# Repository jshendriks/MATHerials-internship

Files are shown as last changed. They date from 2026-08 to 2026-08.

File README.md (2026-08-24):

# MATHerials internship
As part of the masters Science Education and Communication at Utrecht University I was an intern at Hogeschool Utrecht at the lectorate of mathematical and analytical faculties for professionals. During the internship I developed a prototype for MATHerials based on a digital action-based embodied design developed and researched by the Freudenthal Institute at Utrecht University (https://embodieddesign.sites.uu.nl/). 

## Main features
The prototype can be used to explore the connection between the x-coordinate of the sine graph and the unit circle. The idea is that a user manipulates two grips, one along a line and the other on a circle. Feedback on the movement of the user is provided by a light (or something else depending on your needs). The feedback mechanism is hidden inside a box. This mechanism uses a pulley system to translate circular movement into linear movement and an electrical circuit. The electrical circuit contains a hall effect which closes the circuit if it is near a magnet. The pulley system indicates the length which needs to be travelled by the grip in the line using a magnet. The magnet on the pulley system closes the electrical circuit. The closed electrical circuit turns on the LED and indicates that the user has correctly moved the grips on the lid of the prototype.

## Build instructions
This repository has three folders, namely:
- Documents
- Hardware
- Results
### Documents
The folder Documents contains documentation on the prototype such as the literature on embodied cognition, mathematics anxiety and the digital action-based embodied design on which the prototype is based. Moreover, this directory also contains the internship report concerning this prototype.
### Hardware
The folder Hardware contains files which can be used to reconstruct the prototype yourself such as the step files for the 3D printed parts and ai files for laser cutting the box and the lid of the box.
### Results
The folder Results contains pictures of the prototype made during the internship.

## Outcomes
The main outcome of the internship is a prototype for a physical action-based embodied design. 

## Funding and guidance
The prototype was funded by @LilisProtoLab (https://github.com/LilisProtoLab) and the Freudenthal Institute. Moreover, while building the prototype I have received guidance and advice on how to build the prototype from the team at @LilisProtoLab. Thank you all so much!

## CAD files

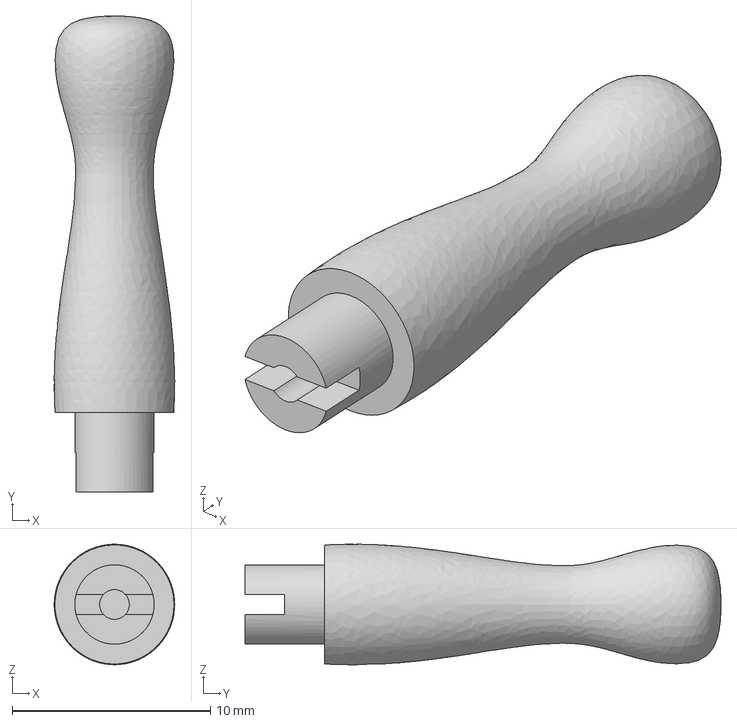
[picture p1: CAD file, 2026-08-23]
Hardware/3D printing/Handle.step
6.08 x 24.0 x 6.08 mm

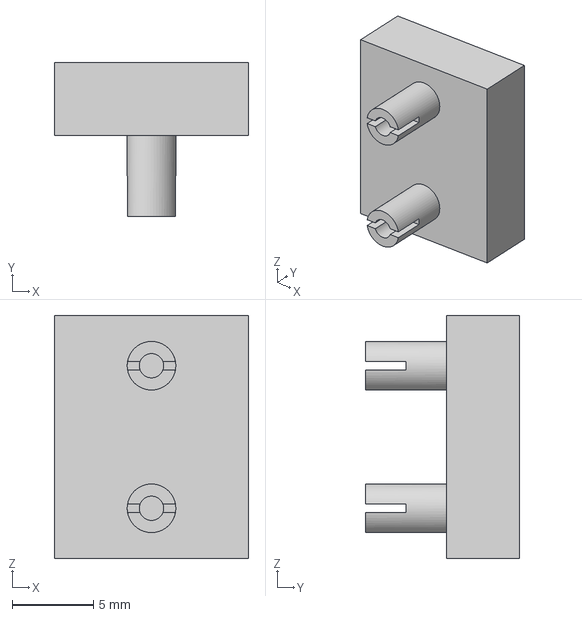
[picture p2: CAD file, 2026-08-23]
Hardware/3D printing/MagnetHolderUpper.step
12.0 x 9.50 x 15.0 mm

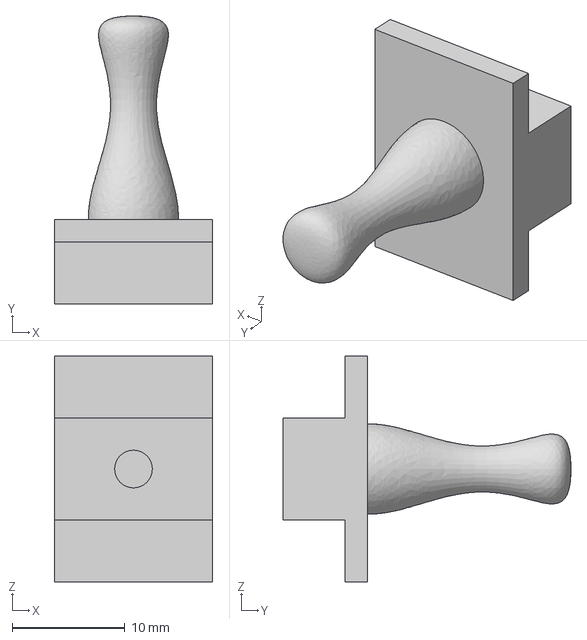
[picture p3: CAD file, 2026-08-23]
Hardware/3D printing/LinearHandleUpper.step
14.0 x 25.5 x 20.0 mm

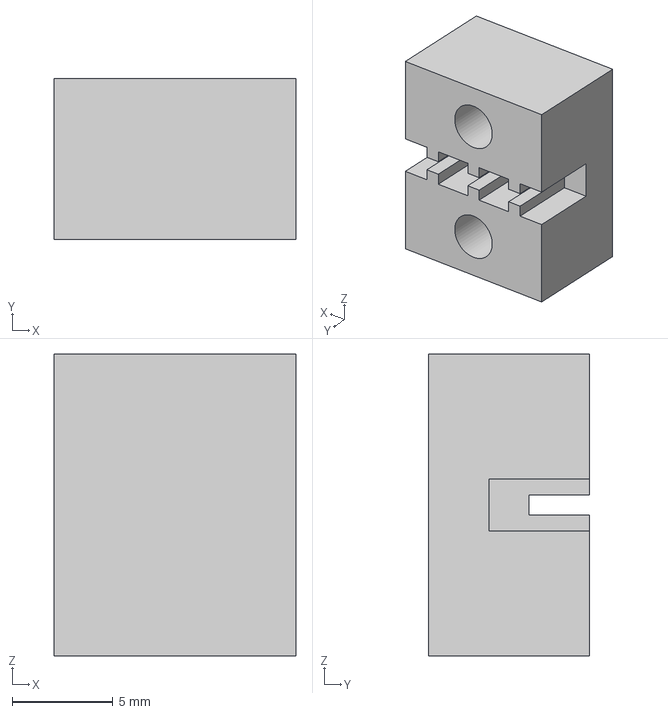
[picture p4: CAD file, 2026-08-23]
Hardware/3D printing/MagnetHolderLower.step
12.0 x 8.00 x 15.0 mm

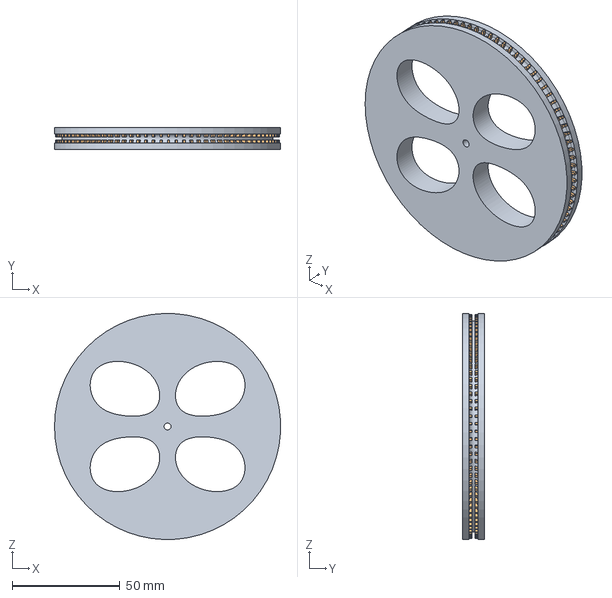
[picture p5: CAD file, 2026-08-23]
Hardware/3D printing/BallPulleyRight.step
104.9 x 10.0 x 105.0 mm

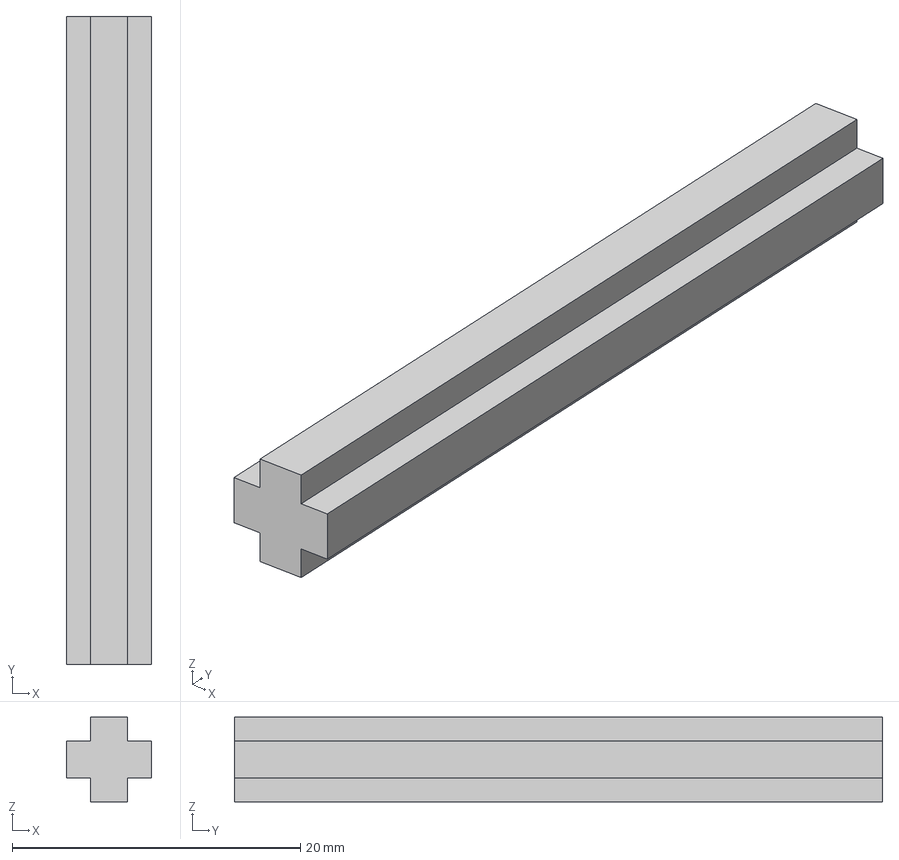
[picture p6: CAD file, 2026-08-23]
Hardware/3D printing/Axle.step
5.90 x 45.0 x 5.90 mm

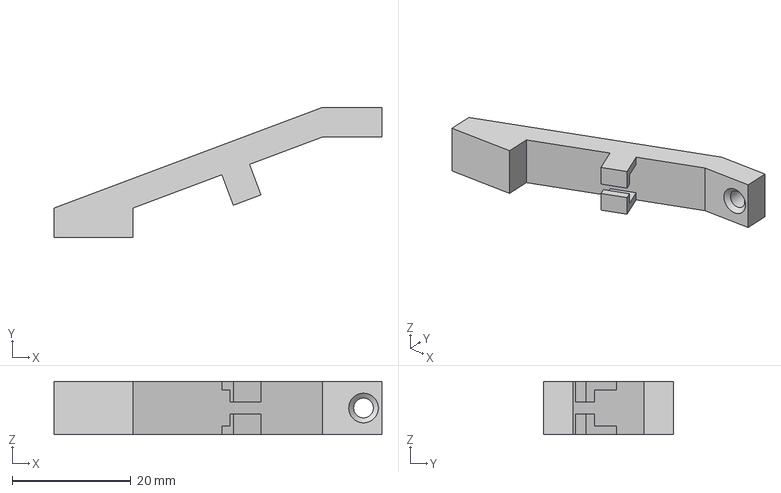
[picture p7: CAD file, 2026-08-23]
Hardware/3D printing/HallEffect.step
55.3 x 22.0 x 9.00 mm

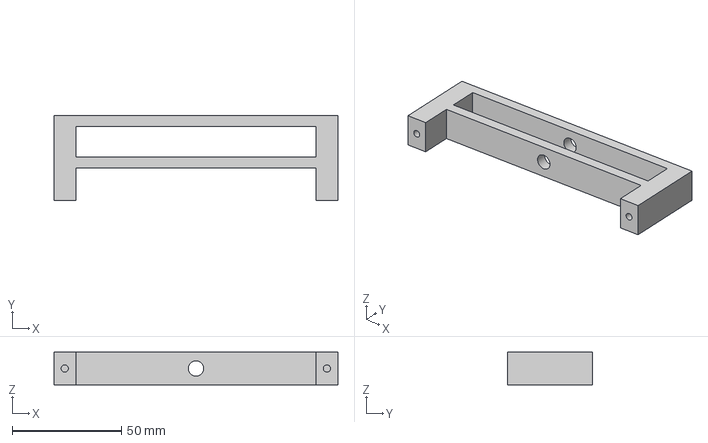
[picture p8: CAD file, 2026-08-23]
Hardware/3D printing/Gearbox.step
130.0 x 39.0 x 15.0 mm

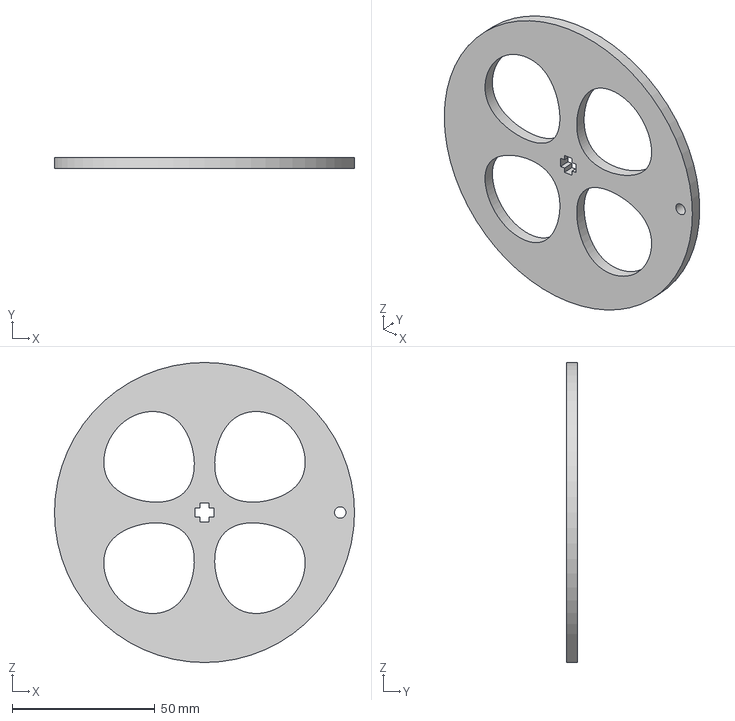
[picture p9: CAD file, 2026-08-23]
Hardware/3D printing/Wheel.step
105.0 x 4.00 x 105.0 mm

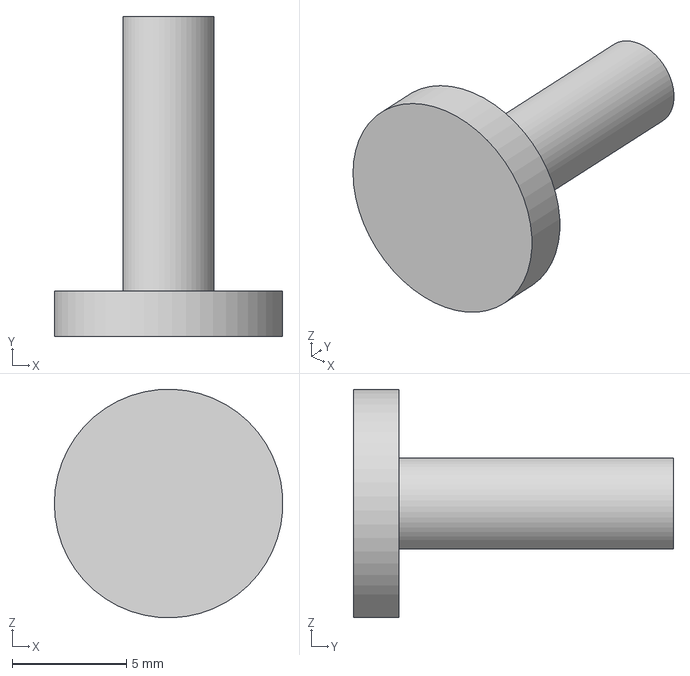
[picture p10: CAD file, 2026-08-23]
Hardware/3D printing/PlaceHolder.step
9.99 x 14.0 x 10.00 mm

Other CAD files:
Hardware/3D printing/BallPulleyLeft.step

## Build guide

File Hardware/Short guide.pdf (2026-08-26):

## MATHerials Short guide to building the prototype

Jagna Hendriks

August 26, 2026

1 Introduction

In this document we will shortly discuss how to replicate the prototype which is discussed in the report which can be found in the directory Documents in subdirectory Report. To build the prototype you will need the les in the directory named Hardware.

2 The box

In the subdirectory Laser cutting you can nd two les. The le named Box.ai contains the outline of the box and the le Lid.ai contains the outline of the lid for this prototype. These les can be used to laser cut the box. For the rst prototype 4mm triplex was used for both the box and the lid.

The lid can be attached to the box using hinges. The hinges need to be attached to the side of the little circular hole in the lid. The precise placement of these hinges on that particular side of the lid is left to the builder.

3 | The feedback mechanism
3.1 | 3D printed parts

In this subsection the names of the parts are the names of the step les.

Most of the parts for the feedback mechanism and the grips were 3D printed for the rst prototype. The step les for the parts can be found in subdirectory 3D printing. For these parts I used eSun petg lament and a nozzle of 0.3 or 0.4 mm. For smaller parts such as the axle or the magnet holder I used a smaller nozzle for better results.

First you need to know how to assemble the mechanism underneath the circle in the lid. This mechanism includes the gearbox, axle, ballpulley left, handle, and the wheel.The axle goes through the holes in the gearbox. Underneath the gearbox the ballpulley (left) can be placed and the axle should go through the hole in the middle of the ballpulley. The wheel can be placed on top of the gearbox such that the axle goes through the middle of the wheel. The handle can be placed in the hole on the edge of the wheel.

The gearbox needs to be attached to the box. This can be done by drilling two holes in the box for 3.5 mm screws with a length of approximately 8 mm. Use the 3D printed gearbox, wheel, ballpulley wheel (left), and lid to determine where the gearbox needs to be attached and where to drill the holes in the box. The gearbox needs to be placed such that the handle in the wheel moves easily through the circle in the lid.

Once the gearbox is attached to the box, you can determine where placeholder for the ballpulley wheel (right) needs to be attached. The placeholder needs to be placed such that the ballpulley (right) is on the other end of the box compared to the gearbox and the ballchain needs to reach to the end of the line in the lid. In the prototype this placeholder is glued to the box with gorilla glue.

1

For the pulley a ballchain with a diameter of 2.4 mm is used. The ballpulley wheels are made to accomodate a ballchain with a 2.4 mm diameter. The ballchain needs to be spanned between the ballpulley wheels.

The handle in the line consists of three parts, namely linear handle lower and upper, and the step le named hall eect. This handle needs to be attached to the lid of the box. Linear handle upper goes on top of the box such that it ts into the line in the lid. The linear handle lower needs to be screwed onto the upper part and resides on the other side of the lid (the inside) with a screw of 3.5 mm and a length between 5 and 8 mm. Make sure that the hole in the linear handle lower faces away from the small hole in the lid. Now the hall eect (arm) needs to be screwed to the linear handle lower with a 3.5 mm screw with a length of around 5 mm. The hall eect (arm) needs to face away from the small hole in the lid.

Now the magnet holder needs to be placed on the ballchain. The magnet needs to be placed such that it is at the beginning of the line in lid when the handle in the wheel is just above the wooden line in the circle (in the lid). The magnet holder lower should be placed under the ballchain and the ballchain needs to go through it. Then the magnet holder upper needs to be placed on top of the lower part. The magnet holder upper has a circular hole in it. There a magnet should be placed.

3.2 The electrical circuit

For the electrical circuit a breadboard is used. This makes it easier to replace parts or change the circuit. The breadboard is glued to the lid next to the little hole in the lid.

The little hole in the lid is meant for an LED. The rectangular hole is for an on and o switch. A hall eect (sensor) needs to be glued to the arm extending from the handle attached to the lid. It needs to be glued such that the wires go in the direction of the LED. Moreover, you will need an energy source. In the rst prototype four triple A batteries were used as the energy source for the electrical circuit. The electrical circuit should be assembled as represented in Figure 1.

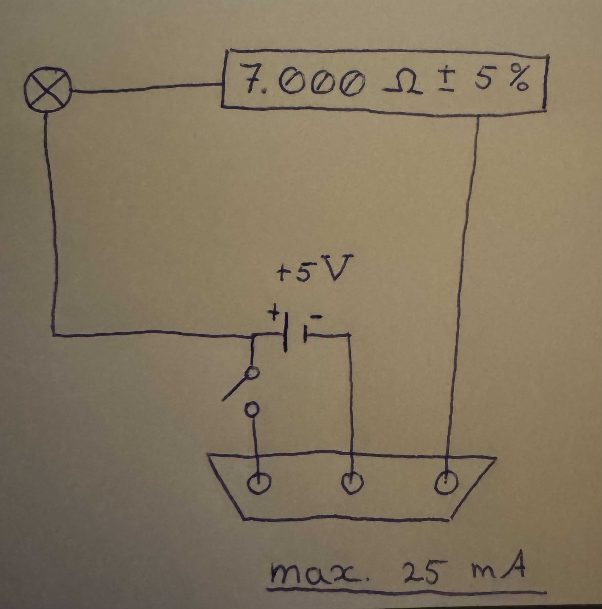
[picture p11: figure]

Figure 1: Representation of electrical circuit.

2

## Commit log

2026-08-23 Added the step files for assembly and ai files for laser cutting the box
    [As_voorGearBoxv3.step, BallPulleyRight_v1.step, BallPulley_v1.step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]
2026-08-24 Added pictures of prototype to Results directory
2026-08-26 Edited names of step files
    [Axle.step, BallPulleyLeft.step, BallPulleyRight.step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]
2026-08-26 Changed the name of step file
    [HallEffect.step]
2026-08-26 Made and added a first version of a short building guide for prototype
